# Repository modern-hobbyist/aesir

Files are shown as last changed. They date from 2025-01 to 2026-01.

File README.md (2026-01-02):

# Project Aesir: Custom Keyboard PCB Designs

> ** Many of these boards are still works in progress **

**Project Aesir** is a collection of custom keyboard PCB designs created using KiCad, aimed at keyboard enthusiasts and DIY makers. Each project in this collection was designed to scratch a specific itch, fill a need, or address a particular problem I had with traditional mechanical keyboards, from a template for a standard keyboard PCB using the STM32F072CBT6 microcontroller to a split ergonomic keyboard design with a modular numpad.

I initially started this collection as a personal respository of templates to get my new projects on the ground running faster, but it has gradually grown to include several board designs I've completed. Make sure to check back in periodically as I add new boards to my collection!

## Included Projects
1. **Heimdall**: A full-sized keyboard PCB designed for customization and personal use.
2. **Hermod**: A split ergonomic keyboard design for those seeking an ergonomic, portable build. Featuring a magnetically detachable AND reversible numpad!
3. **Hermod Mk. II**: A remake of the original Hermod with an upgraded STM32G474CET6 MCU, supporting Choc V2 and Gateron KS-33 low profile switches. Including an updated thumb cluster for better ergonomics and an extra key.
3. **Hermod Mk. II - MX**: A remake of the original Hermod, this time with **MX Spacing**. Same as *8Hermod Mk. II** -- supporting Choc V2 and Gateron KS-33 switches.
4. **Hermod Mk. II - MX - North**: Same as **Hermod Mk. II - MX** but with North facing switches for better shine through keycap legend appearance.
5. **Hermod Mk. III**: A continuation of **Hermod Mk. II - MX - North** with several component upgrades for easier/cheaper sourcing (e.g. SRV05-4 for ESD).
6. **Mist**: A full sized keyboard with a new take on the spacebar--replacing it with thumb clusters. It also supports Cherry MX/Gateron Normal Profile or Gateron KS-33 Low Profile Switches.
7. **Mist UDB**: Same as **Mist**, but using a unified daughter board to offload the ESD and USB protection.
8. **Mist UDB - Mk. II**: Same as **Mist UDB** but with proper support for the Gateron Low profile stabilizers as well as standard PCB mount stabilizers via mousebitten PCB cutouts.
3. **STM32F072CBT6 Standard Template**: A blank template for creating your own keyboard designs with the STM32F072CBT6 microcontroller.
4. **STM32F072CBT6 Split Template**: A blank template for creating your own split keyboard designs with the STM32F072CBT6 microcontroller.

## Getting Started

> Note: There may be footprints I've created or manually altered that aren't packaged with this repository, so if you come across something missing, please create an issue and I'll get it updated!

### Requirements
- **KiCad**: Download and install the latest version of [KiCad](https://www.kicad.org/download/).
- **PCB Manufacturer**: These projects were developed in collaboration with PCBWay. Each sub-project will have a link to the project on PCBWay's project sharing platform so you can order them with the click of a button.
- **Plugins**: There are a few KiCad plugins that you can install that will help with building these PCB's as well as one library of keyswitches:
  - [marbastlib Keyswitch Symbol Library](https://github.com/ebastler/marbastlib)
  - [kicad-kbplacer](https://github.com/adamws/kicad-kbplacer)
  - [PCBWay Order Plugin](https://github.com/pcbway/PCBWay-Plug-in-for-Kicad)

### Steps
1. Clone this repository to your local machine.
    ```bash
    git clone https://github.com/modern-hobbyist/aesir
    ```
2. Open the desired KiCad project in your KiCad software.
3. Customize the layout, add your own components, and make any modifications to fit your needs.
4. Export the Gerber files for your chosen PCB manufacturer.
5. Build and assemble your keyboard!

## Contributing
Contributions to **Project Aesir** are welcome! Whether it's improving existing designs, adding new features, or creating entirely new layouts, feel free to open a pull request.

### Contribution Guidelines
1. Fork the repository.
2. Make your changes on a new branch.
3. Submit a pull request with a clear description of your contribution.

## Disclaimer
These designs are provided as-is, without warranty of any kind. I am not liable for any damages, malfunctions, or issues that may arise from using or modifying these designs, including but not limited to hardware damage, injury, or other unintended consequences. By using these designs, you agree to take full responsibility for any results, modifications, or assembly errors.

## License
This project is licensed under the MIT License. See the [LICENSE](LICENSE) file for details.

## Contact
For questions or collaboration inquiries, feel free to create an issue, reach out to me on GitHub or Discord or via my [YouTube channel](https://www.youtube.com/ModernHobbyist).

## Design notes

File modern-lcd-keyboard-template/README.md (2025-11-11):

# Modern LCD Keyboard Template

> **Note:** This PCB is untested. I made updates to this design to address issues I had with the previous version, but I haven't ordered boards, nor have I written the matching firmware for it.

This is a starter template for a Keyboard PCB to help you get started quickly with the right footprints and supplemental components to get it done right.

## Features
- TBD

## Specifications

- **Microcontroller**: STM32G474CETx
- **Key Layout**: Split layout with additional keys for layers and macros.
- **Display**: 2.2" LCD (320x240 resolution) per half.
- **Lighting**: SK6812 Mini RGB LEDs.
- **Switches**: Kailh Choc Low Profile.

## License

This project is licensed under the MIT License. See the [LICENSE](../LICENSE) file for details.

## Acknowledgments

- The QMK community for their amazing firmware.
- Adafruit for the GFX library support.
- Inspiration from the mechanical keyboard enthusiast community.

---

For more information, check out the [Modern Hobbyist YouTube channel](https://www.youtube.com/ModernHobbyist) for videos about this project!

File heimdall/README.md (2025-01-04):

# Heimdall: Full-Sized Custom Keyboard PCB

## Overview
A brief description of the Heimdall project.

## Features
- List of features for the Heimdall keyboard (e.g., full-sized layout, RGB support).

## Requirements
- List of necessary components (e.g., STM32F072CBT6 microcontroller, WS2812B LEDs, etc.).
- Software requirements (e.g., KiCad, QMK firmware).

## Getting Started
1. Clone the repository.
2. Open the project in KiCad.
3. Customize the layout, add components, etc.
4. Export Gerber files and order the PCB.
5. Assemble and program the keyboard.

## Usage
- Instructions on how to use the keyboard, flash firmware, etc.

## Contributing
- Fork the repository.
- Submit a pull request.

## Disclaimer
These designs are provided as-is. I am not liable for any damages or issues.

## License
Licensed under the MIT License. See the [LICENSE](../LICENSE) for more details.

## Contact
For inquiries, contact via GitHub or YouTube.

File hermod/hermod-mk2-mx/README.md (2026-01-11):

# Hermod Mk. II - MX

> **Note:** This PCB is untested. I made updates to this design to address issues I had with the previous version, but I haven't ordered boards, nor have I written the matching firmware for it.

Hermod Mk. II is a redesign of my original Hermod split keyboard, which in turn was my second keyboard design ever! Some issues that were resolved in this version include:
- Better Pin choices for PWM Channels, Mk. I had some issues with timers overlapping
- Added a handedness pin 
  - Allows me to avoid using flash to store handedness
- Switched to Full Duplex split comms
- Mk.I was missing a 5.1kΩ resistor on the split serial line and this switched fixes that.
- Switched to `STM32G474CETx` from the `STM32F072CBT6`
  - More Ram, more flash, more fun. Didn't have enough ram for fun graphics on the LCD
- Added PWM Backlight control for the LCD Display 

Furthermore, this is the **MX Spacing variant**. While it is functionally identically to the Hermod Mk. II, this layout is spaced in a 19.05x19.05 grid, which makes it compatible with the [Tai-Hao keycaps](https://shop.tai-hao.com/products/98white-1) highlighted in the ZSA Voyager.

## Features

- **Split Design**: Ergonomic split layout for improved typing comfort.
- **Detachable Numpad**: Magnetically detachable and reversible numpad that can connect to either half.
- **Dual LCD Displays**: Each half features a 2.2" LCD for customizable graphics and real-time information.
- **QMK Firmware**: Fully programmable and customizable using QMK.
- **Per-Key RGB Lighting**: Vibrant, individually addressable RGB LEDs for endless customization.
- **Hot-Swappable Switch Sockets**: Easily swap out switches without soldering.
- **Open Source Hardware**: Schematics and design files available for personal customization.

## Specifications

- **Microcontroller**: STM32G474CETx
- **Key Layout**: Split layout with additional keys for layers and macros.
- **Display**: 2.2" LCD (320x240 resolution) per half.
- **Lighting**: SK6812 Mini RGB LEDs.
- **Switches**: Kailh Choc Low Profile.

## License

This project is licensed under the MIT License. See the [LICENSE](../LICENSE) file for details.

## Acknowledgments

- The QMK community for their amazing firmware.
- Adafruit for the GFX library support.
- Inspiration from the mechanical keyboard enthusiast community.

---

For more information, check out the [Modern Hobbyist YouTube channel](https://www.youtube.com/ModernHobbyist) for videos about this project!

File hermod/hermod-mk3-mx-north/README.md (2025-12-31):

# Hermod Mk. III - MX North

> **Note:** This PCB is untested. I made updates to this design to address issues I had with the previous version, but I haven't ordered boards, nor have I written the matching firmware for it.

Hermod Mk. III is a redesign of my original Hermod split keyboard. Some issues that were resolved in this version include:
- Updated from the PRTR5V0U2X,215 to the SRV05-4 since the former is out of stock everywhere.

Furthermore, this is the **NORTH FACING** MX Spacing variant. While it is functionally identically to the Hermod Mk. II, this layout is spaced in a 19.05x19.05 grid, which makes it compatible with the [Tai-Hao keycaps](https://shop.tai-hao.com/products/98white-1) highlighted in the ZSA Voyager. Also, the switches are rotated 180• from the previous versions so that the LED's are better aligned with shine-through keycaps. 

**Note:** This keyboard supports KS-33 and Choc V2 switches in an MX spacing. It does not support standard MX or Gateron switches. The reasoning for that is that this keyboard was intended to be as low profile as possible (e.g. USB C midmount instead of standard USB C sockets). 

## SMD BOMs
These BOMs exclude the switch hotswap sockets, purchase your sockets of choice (either KS-33 HS or Choc V2 HS sockets)
- Left: https://www.digikey.com/en/mylists/list/ACSWS99OKK
- Right: https://www.digikey.com/en/mylists/list/SVQS1DIITH
- Numpad: 
  - Just need 20x Diodes for the switches: https://www.digikey.com/en/products/detail/mcc-micro-commercial-components/1N4148W-TP/717196
  
## Hardware BOM
- TODO

## Features

- **Split Design**: Ergonomic split layout for improved typing comfort.
- **Detachable Numpad**: Magnetically detachable and reversible numpad that can connect to either half.
- **Dual LCD Displays**: Each half features a 2.2" LCD for customizable graphics and real-time information.
- **QMK Firmware**: Fully programmable and customizable using QMK.
- **Per-Key RGB Lighting**: Idividually addressable RGB LEDs for endless customization.
- **Hot-Swappable Switch Sockets**: Easily swap out switches without soldering.
- **Open Source Hardware**: Schematics and design files available for personal customization.
- **Combo Switch Footprints**: Choose between KS-33 or Choc V2 hotswap sockets.

## Specifications

- **Microcontroller**: STM32G474CET6
- **Key Layout**: Split layout with additional keys for layers and macros.
- **Display**: 2.2" LCD (320x240 resolution) per half.
- **Lighting**: SK6812 Mini RGB LEDs.
- **Switches**: Kailh Choc Low Profile.

## License

This project is licensed under the MIT License. See the [LICENSE](../LICENSE) file for details.

## Acknowledgments

- The QMK community for their amazing firmware.
- Adafruit for the GFX library support.
- Inspiration from the mechanical keyboard enthusiast community.

---

For more information, check out the [Modern Hobbyist YouTube channel](https://www.youtube.com/ModernHobbyist) for videos about this project!

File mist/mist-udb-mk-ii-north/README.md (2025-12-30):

# Mist

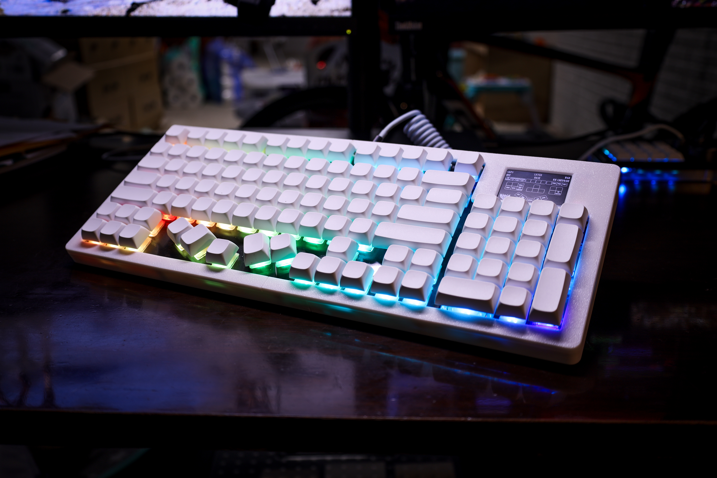
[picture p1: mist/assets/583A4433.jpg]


**Mist** is my take on a full size keyboard, but with some upgrades I carried over from my second keyboard build--**[Hermod](https://github.com/modern-hobbyist/aesir/tree/main/hermod-mk2)**. Furthermore, this is the UDB version of **Mist**, which stands for Unified Daughter Board

Aside from the UDB connector and the lack of USB-C/on-board ESD protection circuitry, this keyboard is functionally identical to the base **Mist** keyboard.

This project is open source, so I'll do my best to keep it updated as questions come in. I can't guarantee I'll always have time to respond, but if you have questions you can reach out on [my Discord server](https://discord.gg/68WXGsjqJp) or on the [Keyboard Atelier Discord](https://discord.gg/b7vwhHS).

## Why?

1. First of all, I'm addicted to designing custom keyboards now, so jot that down.
2. I have two children now, and while I love my split keyboard, typing with one hand is 100 times more difficult and time consuming on a split.
3. Related to above, I wanted a keyboard that would appeal to the non-split community, but also incorporated all the features I loved mose about my split build.

## Features

- **2.2" LCD Display**: A 2.2" LCD Display to show keyboard state, stats, and any fun animations I can think of.
- **Thumb Clusters in Place of Spacebar**: I loved the thumb clusters from my split keyboard and the giant spacebar is such a waste of space!
- **Connector for Unified Daughter Board**: A Unified Daughter Board extracts all the ESD and over-voltage protection from the main PCB and allows for more complex case shapes.
- **Per-Key RGB Lighting**: Vibrant, individually addressable RGB LEDs for endless customization.
- **KS-33 + MX/Gateron Normal Profile Hot-Swappable Switch Sockets**: Support for either KS-33 low-profile or MX style (Cherry or Gateron Normal profile) switches.
- **QMK Firmware**: Fully programmable and customizable using QMK.
- **Standard QWERTY Layout and Keymap**: The layout we all grew up learning to type on!

## Specifications

- **Microcontroller**: STM32G474RETx
- **Display**: 2.2" LCD (320x240 resolution) per half.
- **Lighting**: SK6812 Mini RGB LEDs.

## BOM
> Note: I have not finished building a KS-33 version of this keyboard. However, the only difference is the hotswap sockets you use (and the corresponding switches/keycaps). Also, there shouldn't be any issue using the existing case design with the KS-33 version.

### Electronics

- [Digikey Parts LIst](https://www.digikey.com/en/mylists/list/XUNNWUFIT7)
- [ILI9341 LCD](https://www.aliexpress.us/item/2255800032844649.html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)
- [PCBWay Project](https://www.pcbway.com/project/shareproject/Custom_Mechanical_Keyboard_7a40c23a.html)
  - > Note: If you are ordering assembled PCBs from the PCBWay Project, it may take a few cycles to smooth out any BOM hiccups.
- [Unified Daughter Board](https://cannonkeys.com/products/unified-daughterboard-and-jst-cable?variant=41613867843695)
- [Hotswap Sockets I used](https://www.aliexpress.us/item/3256807081236706.html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)
- [Keycaps I used](https://www.aliexpress.us/item/3256805029855838.html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)
- [Switches of Choice](https://a.co/d/3fji9Gi)
- [Stabilizers of CHoice](https://a.co/d/hJjX7h8)

### Hardware

- [1.5mm Acrylic Sheet](https://a.co/d/8NMezDu)
- [M3x8mm Bolts - x13](https://boltdepot.com/Product-Details?product=13635)
- [M3 Nuts - x4](https://boltdepot.com/Product-Details?product=4773)
- [Heatset Inserts - M3x3mm](https://a.co/d/18Dypq1)
- [3mm Poron Sheet](https://www.aliexpress.us/item/3256804497716681.html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)
- [18x3x3mm gaskets](https://www.aliexpress.us/item/3256804012735285.html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)
- [M2x6mm Nylon Standoffs](https://www.aliexpress.us/item/3256808418665069.html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) - Female - Female
- [M2x3mm screws](https://www.aliexpress.us/item/3256807746050750.html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)
- [8mm Steel Rods](https://a.co/d/39idH9k)

# Tools

- [Heat Set Insert tips](https://a.co/d/3we9tOl)
- 3d Printer
- Allen Wrenches
- Razor Blade
- Soldering Iron
- Computer
- USB C Cable
- Super Glue

## License

This project is licensed under the MIT License. See the [LICENSE](../LICENSE) file for details.

## Acknowledgments

- The QMK community for their amazing firmware.
- Adafruit for the GFX library support.
- Inspiration from the mechanical keyboard enthusiast community.

---

For more information, check out the [Modern Hobbyist YouTube channel](https://www.youtube.com/ModernHobbyist) for videos about this project!

> Also, please let me know in an issue or on Discord if there are issues with this board or the supplementary files so I can get them updated!

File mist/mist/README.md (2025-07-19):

# Mist

> **Note:** This PCB is untested. I am working on getting an order together, but until I can verify it functions as expected, use at your own risk.

**Mist** is my take on a full size keyboard, but with some upgrades I carried over from my second keyboard build--**Hermod**.

## Why?
1. First of all, I've addicted to designing custom keyboards now, so jot that down.
2. I have two children now, and while I love my split keyboard, typing with one hand is 100 times more difficult and time consuming on a split.
3. Related to above, I wanted a keyboard that would appeal to the non-split community, but also incorporated all the features I loved mose about my split build.

## Features

- **2.2" LCD Display**: A 2.2" LCD Display to show keyboard state, stats, and any fun animations I can think of.
- **Thumb Clusters in Place of Spacebar**: I loved the thumb clusters from my split keyboard and the giant spacebar is such a waste of space!
- **Per-Key RGB Lighting**: Vibrant, individually addressable RGB LEDs for endless customization.
- **KS-33 + MX/Gateron Normal Profile Hot-Swappable Switch Sockets**: Support for either KS-33 low-profile or MX style (Cherry or Gateron Normal profile) switches.
- **QMK Firmware**: Fully programmable and customizable using QMK.
- **Standard QWERTY Layout and Keymap**: The layout we all grew up learning to type on!

## Specifications

- **Microcontroller**: STM32G474RETx
- **Display**: 2.2" LCD (320x240 resolution) per half.
- **Lighting**: SK6812 Mini RGB LEDs.

## License

This project is licensed under the MIT License. See the [LICENSE](../LICENSE) file for details.

## Acknowledgments

- The QMK community for their amazing firmware.
- Adafruit for the GFX library support.
- Inspiration from the mechanical keyboard enthusiast community.

---

For more information, check out the [Modern Hobbyist YouTube channel](https://www.youtube.com/ModernHobbyist) for videos about this project!

> Also, please let me know in an issue or on Discord if there are issues with this board or the supplementary files so I can get them updated!

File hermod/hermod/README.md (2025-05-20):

# Hermod Split Keyboard

Hermod is a feature-rich, fully customizable split mechanical keyboard designed for enthusiasts who want the ultimate typing experience. With per-key RGB lighting, dual 2.2" LCD displays, and QMK firmware compatibility, Hermod is both functional and visually stunning.

## Features

- **Split Design**: Ergonomic split layout for improved typing comfort.
- **Detachable Numpad**: Magnetically detachable and reversible numpad that can connect to either half.
- **Dual LCD Displays**: Each half features a 2.2" LCD for customizable graphics and real-time information.
- **QMK Firmware**: Fully programmable and customizable using QMK.
- **Per-Key RGB Lighting**: Vibrant, individually addressable RGB LEDs for endless customization.
- **Hot-Swappable Switch Sockets**: Easily swap out switches without soldering.
- **Open Source Hardware**: Schematics and design files available for personal customization.

## Specifications

- **Microcontroller**: STM32F072CBT6
- **Key Layout**: Split layout with additional keys for layers and macros.
- **Display**: 2.2" LCD (320x240 resolution) per half.
- **Lighting**: SK6812 Mini RGB LEDs.
- **Switches**: Kailh Choc Brown

## Instructions

I haven't yet written out full instructions for this keyboard, but the appropriate BOM and Pick-and-place files should be present to have PCBWay assemble it for you. From there, it's really just a matter of printing all the parts, ordering the right display, switches, keycaps and bolts, then putting it all together!

The firmware is slightly tricky, as each half needs to be flashed with a left or right specific firmware, so I'll try to get instructions for that written soon.

For the time being, here is a link to the latest firmware:
https://github.com/modern-hobbyist/qmk_userspace/releases/tag/latest

## Contributing

Contributions are welcome! Whether you have ideas for features, bug fixes, or design improvements, feel free to open an issue or submit a pull request.

## License

This project is licensed under the MIT License. See the [LICENSE](../LICENSE) file for details.

## Acknowledgments

- The QMK community for their amazing firmware.
- Adafruit for the GFX library support.
- Inspiration from the mechanical keyboard enthusiast community.

---

For more information, check out the [Modern Hobbyist YouTube channel](https://www.youtube.com/ModernHobbyist) for videos about this project!

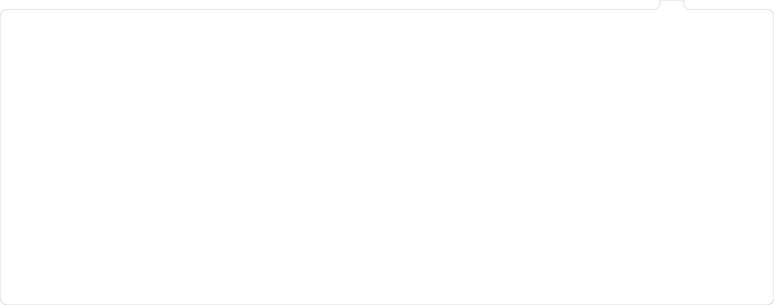
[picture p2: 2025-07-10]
mist/assets/mist-edge-cut-11.png

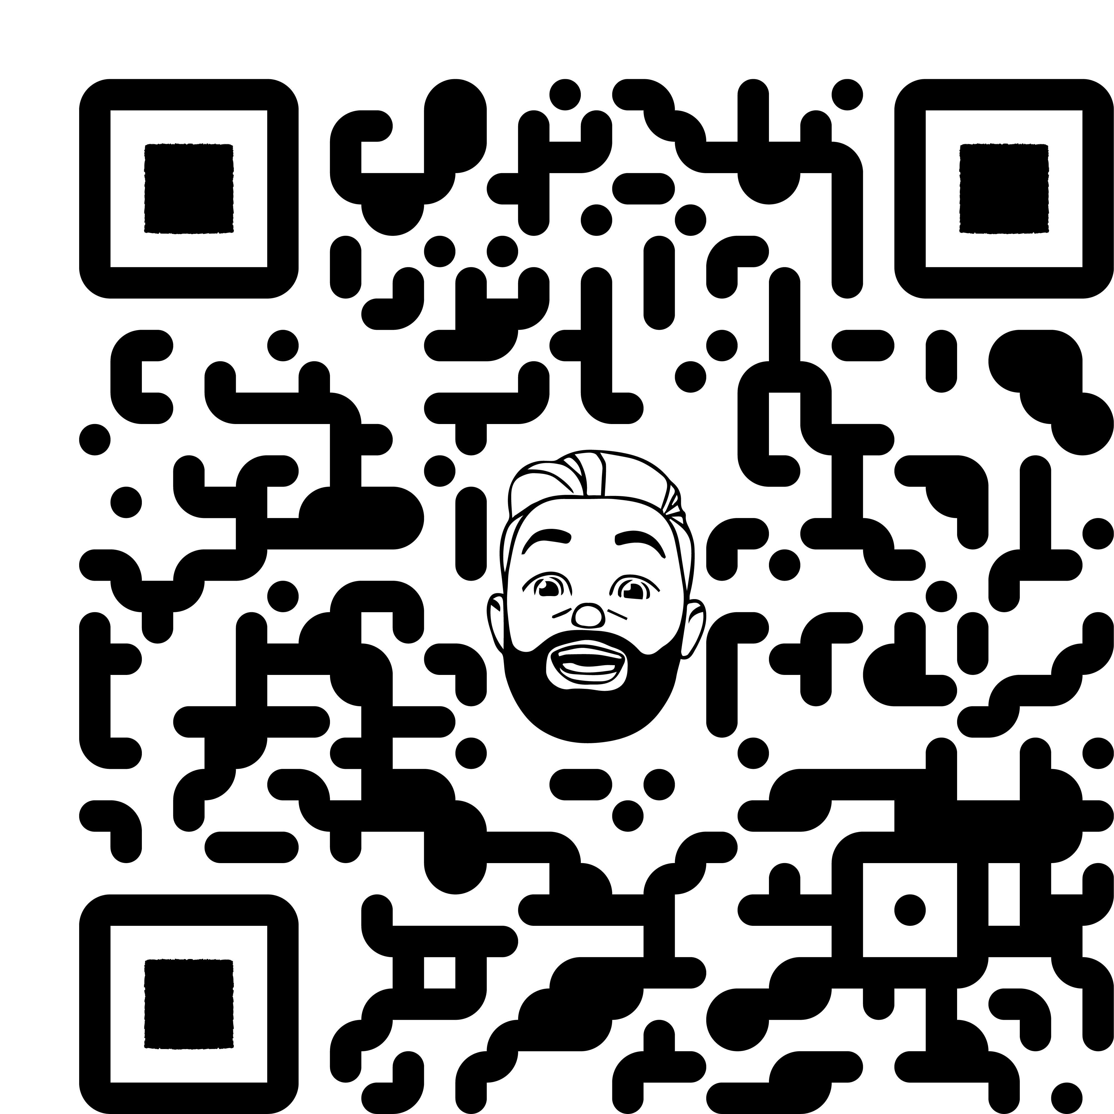
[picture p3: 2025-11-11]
YouTube QR.png

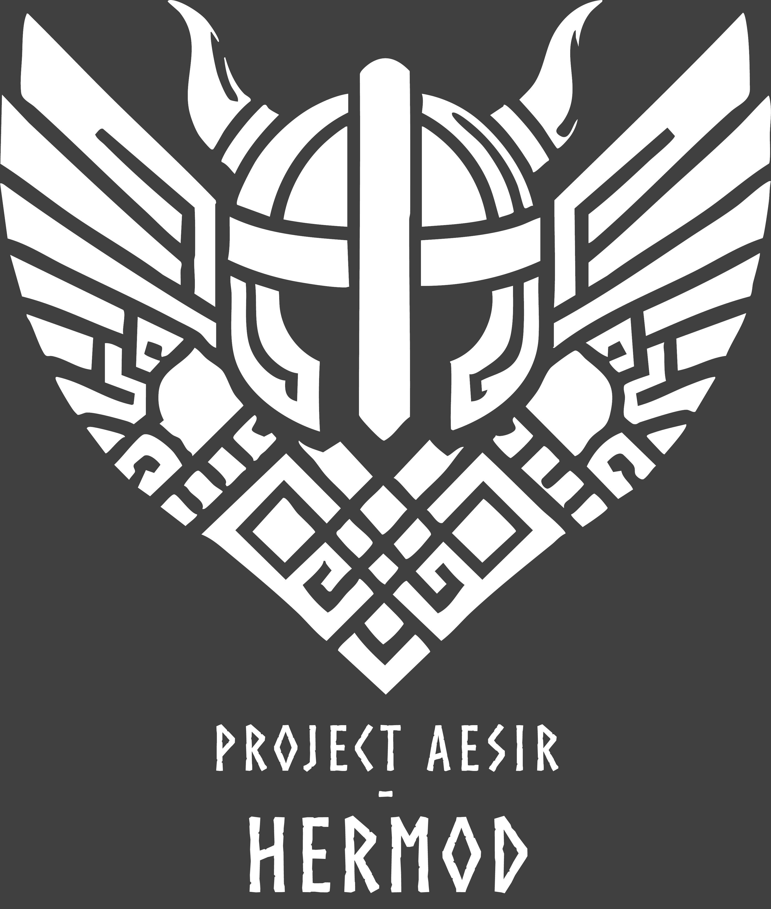
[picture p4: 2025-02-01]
hermod/assets/Asset 11.png

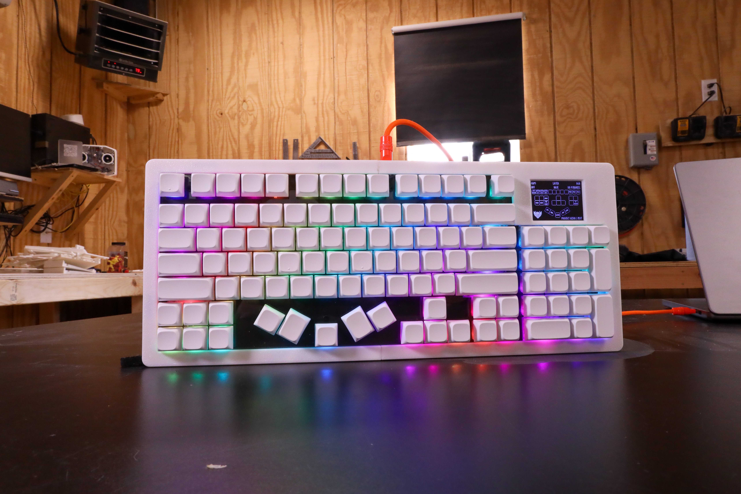
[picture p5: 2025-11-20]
mist/assets/583A4316.jpeg

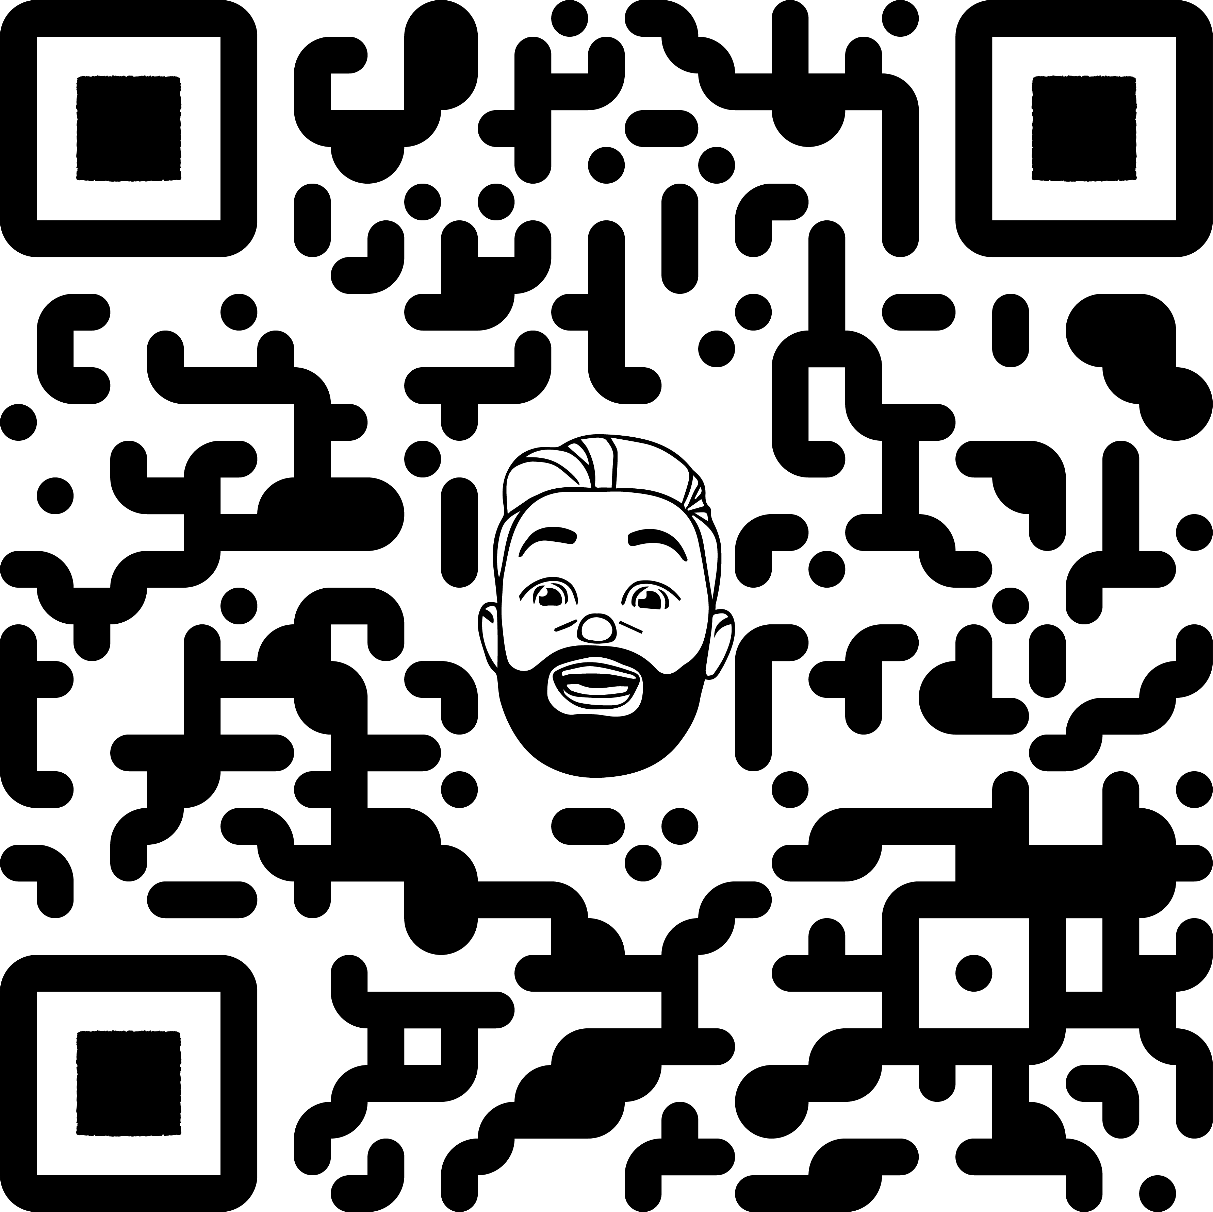
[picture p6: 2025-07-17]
hermod/assets/Asset 31.png

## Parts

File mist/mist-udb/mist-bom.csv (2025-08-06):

Id | Designator | Footprint | Quantity | Designation | Supplier and ref
1 | S4,S6,S7,S5 | STAB_MX_P_2u | 4 | MX_stab
2 | S1,S3 | STAB_MX_P_2.25u | 2 | MX_stab
3 | S2 | STAB_MX_P_2.75u | 1 | MX_stab
4 | U4 | CR2013-MI2120 | 1 | CR2013-MI2120
5 | J2 | PinHeader_1x05_P2.54mm_Vertical | 1 | Conn_01x05
6 | LED44,LED6,LED33,LED8,LED2,LED82,LED25,LED102,LED81,LED49,LED61,LED38,LED17,LED60,LED96,LED52,LED10,LED32,LED22,LED1,LED55,LED40,LED46,LED103,LED83,LED26,LED15,LED36,LED69,LED27,LED21,LED45,LED11,LED68,LED66,LED79,LED86,LED71,LED80,LED100,LED63,LED56,LED16,LED73,LED67,LED72,LED65,LED43,LED31,LED13,LED37,LED89,LED85,LED34,LED76,LED48,LED94,LED84,LED41,LED58,LED28,LED24,LED87,LED74,LED78,LED70,LED9,LED20,LED30,LED75,LED88,LED4,LED3,LED97,LED53,LED12,LED51,LED14,LED29,LED50,LED98,LED19,LED42,LED5,LED23,LED77,LED18,LED90,LED99,LED93,LED101,LED7,LED64,LED95,LED39,LED91,LED54,LED57,LED59,LED35,LED62,LED92,LED47 | LED_choc_6028R | 103 | choc_SK6812MINI-E
7 | C51,C20,C81,C50,C57,C45,C60,C100,C87,C112,C11,C99,C27,C32,C102,C18,C47,C86,C46,C91,C14,C24,C19,C101,C76,C16,C97,C65,C23,C72,C75,C77,C29,C43,C33,C89,C40,C36,C71,C66,C35,C52,C63,C53,C41,C59,C30,C62,C61,C15,C54,C88,C73,C64,C12,C80,C82,C1,C39,C70,C5,C13,C79,C9,C92,C56,C94,C83,C38,C25,C21,C48,C84,C95,C31,C2,C3,C37,C26,C69,C10,C44,C55,C93,C8,C49,C6,C7,C4,C17,C68,C74,C96,C98,C85,C42,C90,C34,C78,C22,C67,C103,C28,C58 | C_0402_1005Metric | 104 | 0.1uF
8 | CH91,CH60,CH96,CH73,CH49,CH46,CH33,CH18,CH58,CH20,CH36,CH45,CH47,CH92,CH32,CH39,CH11,CH70,CH35,CH103,CH24,CH72,CH8,CH31,CH1,CH100,CH4,CH52,CH86,CH57,CH102,CH53,CH75,CH93,CH69,CH14,CH41,CH27,CH68,CH2,CH98,CH76,CH61,CH84,CH85,CH19,CH50,CH87,CH80,CH5,CH63,CH42,CH22,CH99,CH30,CH13,CH28,CH95,CH67,CH21,CH16,CH89,CH77,CH74,CH51,CH23,CH59,CH54,CH79,CH34,CH25,CH78,CH3,CH15,CH37,CH83,CH88,CH64,CH12,CH66,CH48,CH6,CH81,CH65,CH56,CH44,CH40,CH90,CH71,CH82,CH10,CH7,CH94,CH9,CH26,CH17,CH55,CH38,CH62,CH43,CH101,CH97,CH29 | KS-33_MX-Hotswap-1U | 103 | KS33_SW_HS
9 | D25,D27,D89,D71,D76,D78,D96,D17,D58,D72,D95,D10,D16,D47,D23,D13,D87,D69,D70,D52,D92,D3,D34,D81,D14,D66,D21,D33,D85,D56,D30,D83,D74,D104,D9,D43,D19,D59,D11,D84,D1,D53,D20,D105,D50,D80,D12,D77,D55,D60,D28,D93,D100,D15,D32,D37,D94,D26,D73,D18,D8,D68,D2,D46,D103,D64,D39,D42,D75,D29,D22,D79,D49,D99,D44,D98,D88,D51,D6,D57,D86,D45,D7,D5,D31,D54,D61,D62,D101,D35,D48,D36,D102,D63,D67,D97,D38,D90,D91,D24,D4,D82,D65 | D_SOD-123 | 103 | D
10 | C120,C130,C121 | C_0805_2012Metric | 3 | 100n
11 | C127,C128 | C_0402_1005Metric | 2 | 1uF
12 | C107,C104,C108,C109,C105,C106,C110 | C_0402_1005Metric | 7 | 100nF
13 | U6 | SOT95P280X145-5N | 1 | SN74AHCT1G125DBVR
14 | R7 | R_0805_2012Metric | 1 | 120
15 | J1 | Molex_Pico-EZmate_78171-0004_1x04-1MP_P1.20mm_Vertical | 1 | 78171-0004
16 | D41,D40 | D_SOD-123 | 2 | 1N4148
17 | Q3 | SOT-23-3 | 1 | MMUN2133LT1G
18 | RESET1 | SW_SPST_TL3342 | 1 | DFU
19 | R8,R9 | R_0805_2012Metric | 2 | 68k
20 | U5 | LQFP-64_10x10mm_P0.5mm | 1 | STM32G474RETx
21 | U3 | SOT-23 | 1 | XC6206PxxxMR-Regulator_Linear

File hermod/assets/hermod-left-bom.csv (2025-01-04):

Id | Designator | Footprint | Quantity | Designation | Supplier and ref
1 | U7,U6 | Pogo_2.54mm_5p | 2 | ~
2 | U4 | CR2013-MI2120 | 1 | CR2013-MI2120
3 | J2 | PinHeader_1x05_P2.54mm_Vertical | 1 | Conn_01x05
4 | CH17,CH14,CH33,CH11,CH12,CH21,CH5,CH6,CH31,CH26,CH24,CH27,CH25,CH20,CH7,CH8,CH1,CH19,CH10,CH34,CH22,CH3,CH36,CH4,CH13,CH29,CH35,CH18,CH15,CH37,CH32,CH28 | SW_choc_v1_HS_CPG135001S30_1u | 32 | choc_v1_SW_HS
5 | LED36,LED13,LED21,LED32,LED23,LED2,LED20,LED1,LED38,LED29,LED33,LED30,LED18,LED19,LED17,LED8,LED39,LED15,LED24,LED16,LED3,LED4,LED5,LED26,LED27,LED31,LED25,LED9,LED12,LED22,LED34,LED6,LED10,LED11,LED7,LED35,LED28,LED14,LED37 | LED_choc_6028R | 39 | choc_SK6812MINI-E
6 | D2,D33,D28,D20,D1,D36,D30,D22,D39,D14,D24,D13,D12,D19,D16,D25,D11,D3,D37,D15,D18,D23,D34,D21,D6,D5,D35,D4,D31,D29,D38,D10,D26,D8,D17,D7,D32,D9,D27 | D_SOD-123 | 39 | D
7 | C106,C104,C109,C100,C102,C105,C103 | C_0402_1005Metric | 7 | 100nF
8 | C10,C28,C19,C43,C11,C20,C34,C33,C44,C36,C23,C27,C32,C22,C21,C6,C37,C14,C3,C39,C18,C9,C7,C15,C30,C38,C24,C29,C25,C4,C26,C35,C8,C12,C16,C5,C17,C31,C1,C13,C2 | C_0402_1005Metric | 41 | 0.1uF
9 | Q1 | SOT-23-3 | 1 | AO3401A
10 | CH16,CH38,CH23,CH30,CH2,CH39,CH9 | SW_choc_v1_HS_CPG135001S30_1.5u | 7 | choc_v1_SW_HS
11 | RST1,BOOT1 | SW_SPST_TL3342 | 2 | SW_SPST
12 | R2,R3,R1,R4 | R_0402_1005Metric | 4 | 5.1k
13 | C101 | C_0603_1608Metric | 1 | 10uF
14 | C107,C108 | C_0402_1005Metric | 2 | 1uF
15 | F1 | Fuse_1206_3216Metric | 1 | 500mA
16 | U5 | SOT-363_SC-70-6_Handsoldering | 1 | TXB0101
17 | U2 | SOT-143 | 1 | PRTR5V0U2X
18 | U1 | LQFP-48_7x7mm_P0.5mm | 1 | STM32F072CBT6
19 | J1,J3 | USB_C_Receptacle_HRO_TYPE-C-31-M-14 | 2 | USB_C_Receptacle_USB2.0
20 | U3 | SOT-23 | 1 | XC6206PxxxMR-Regulator_Linear
21 | Q2 | SOT-23-3 | 1 | MMUN2233LT1G

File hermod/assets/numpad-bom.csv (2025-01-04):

Id | Designator | Footprint | Quantity | Designation | Supplier and ref
1 | U1,U2 | Pogo_2.54mm_5p | 2 | ~
2 | D3,D2,D20,D5,D10,D13,D6,D9,D14,D16,D7,D18,D11,D4,D17,D1,D8,D15,D12,D19 | D_SOD-123 | 20 | D
3 | CH20,CH2,CH18,CH3,CH5,CH12,CH9,CH10,CH14,CH11,CH19,CH17,CH6,CH8,CH1,CH16,CH7,CH13,CH15,CH4 | SW_choc_v1_HS_CPG135001S30_1u | 20 | choc_v1_SW_HS

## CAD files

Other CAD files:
hermod/hermod-mk2-mx-north/hermod-numpad/numpad-B_Paste.dxf
hermod/hermod-mk2-mx/hermod-numpad/numpad-B_Paste.dxf
hermod/hermod-mk2/hermod-numpad/numpad-B_Paste.dxf
hermod/hermod-mk3-mx-north/hermod-numpad/numpad-B_Paste.dxf
hermod/hermod/hermod-numpad/numpad-B_Paste.dxf

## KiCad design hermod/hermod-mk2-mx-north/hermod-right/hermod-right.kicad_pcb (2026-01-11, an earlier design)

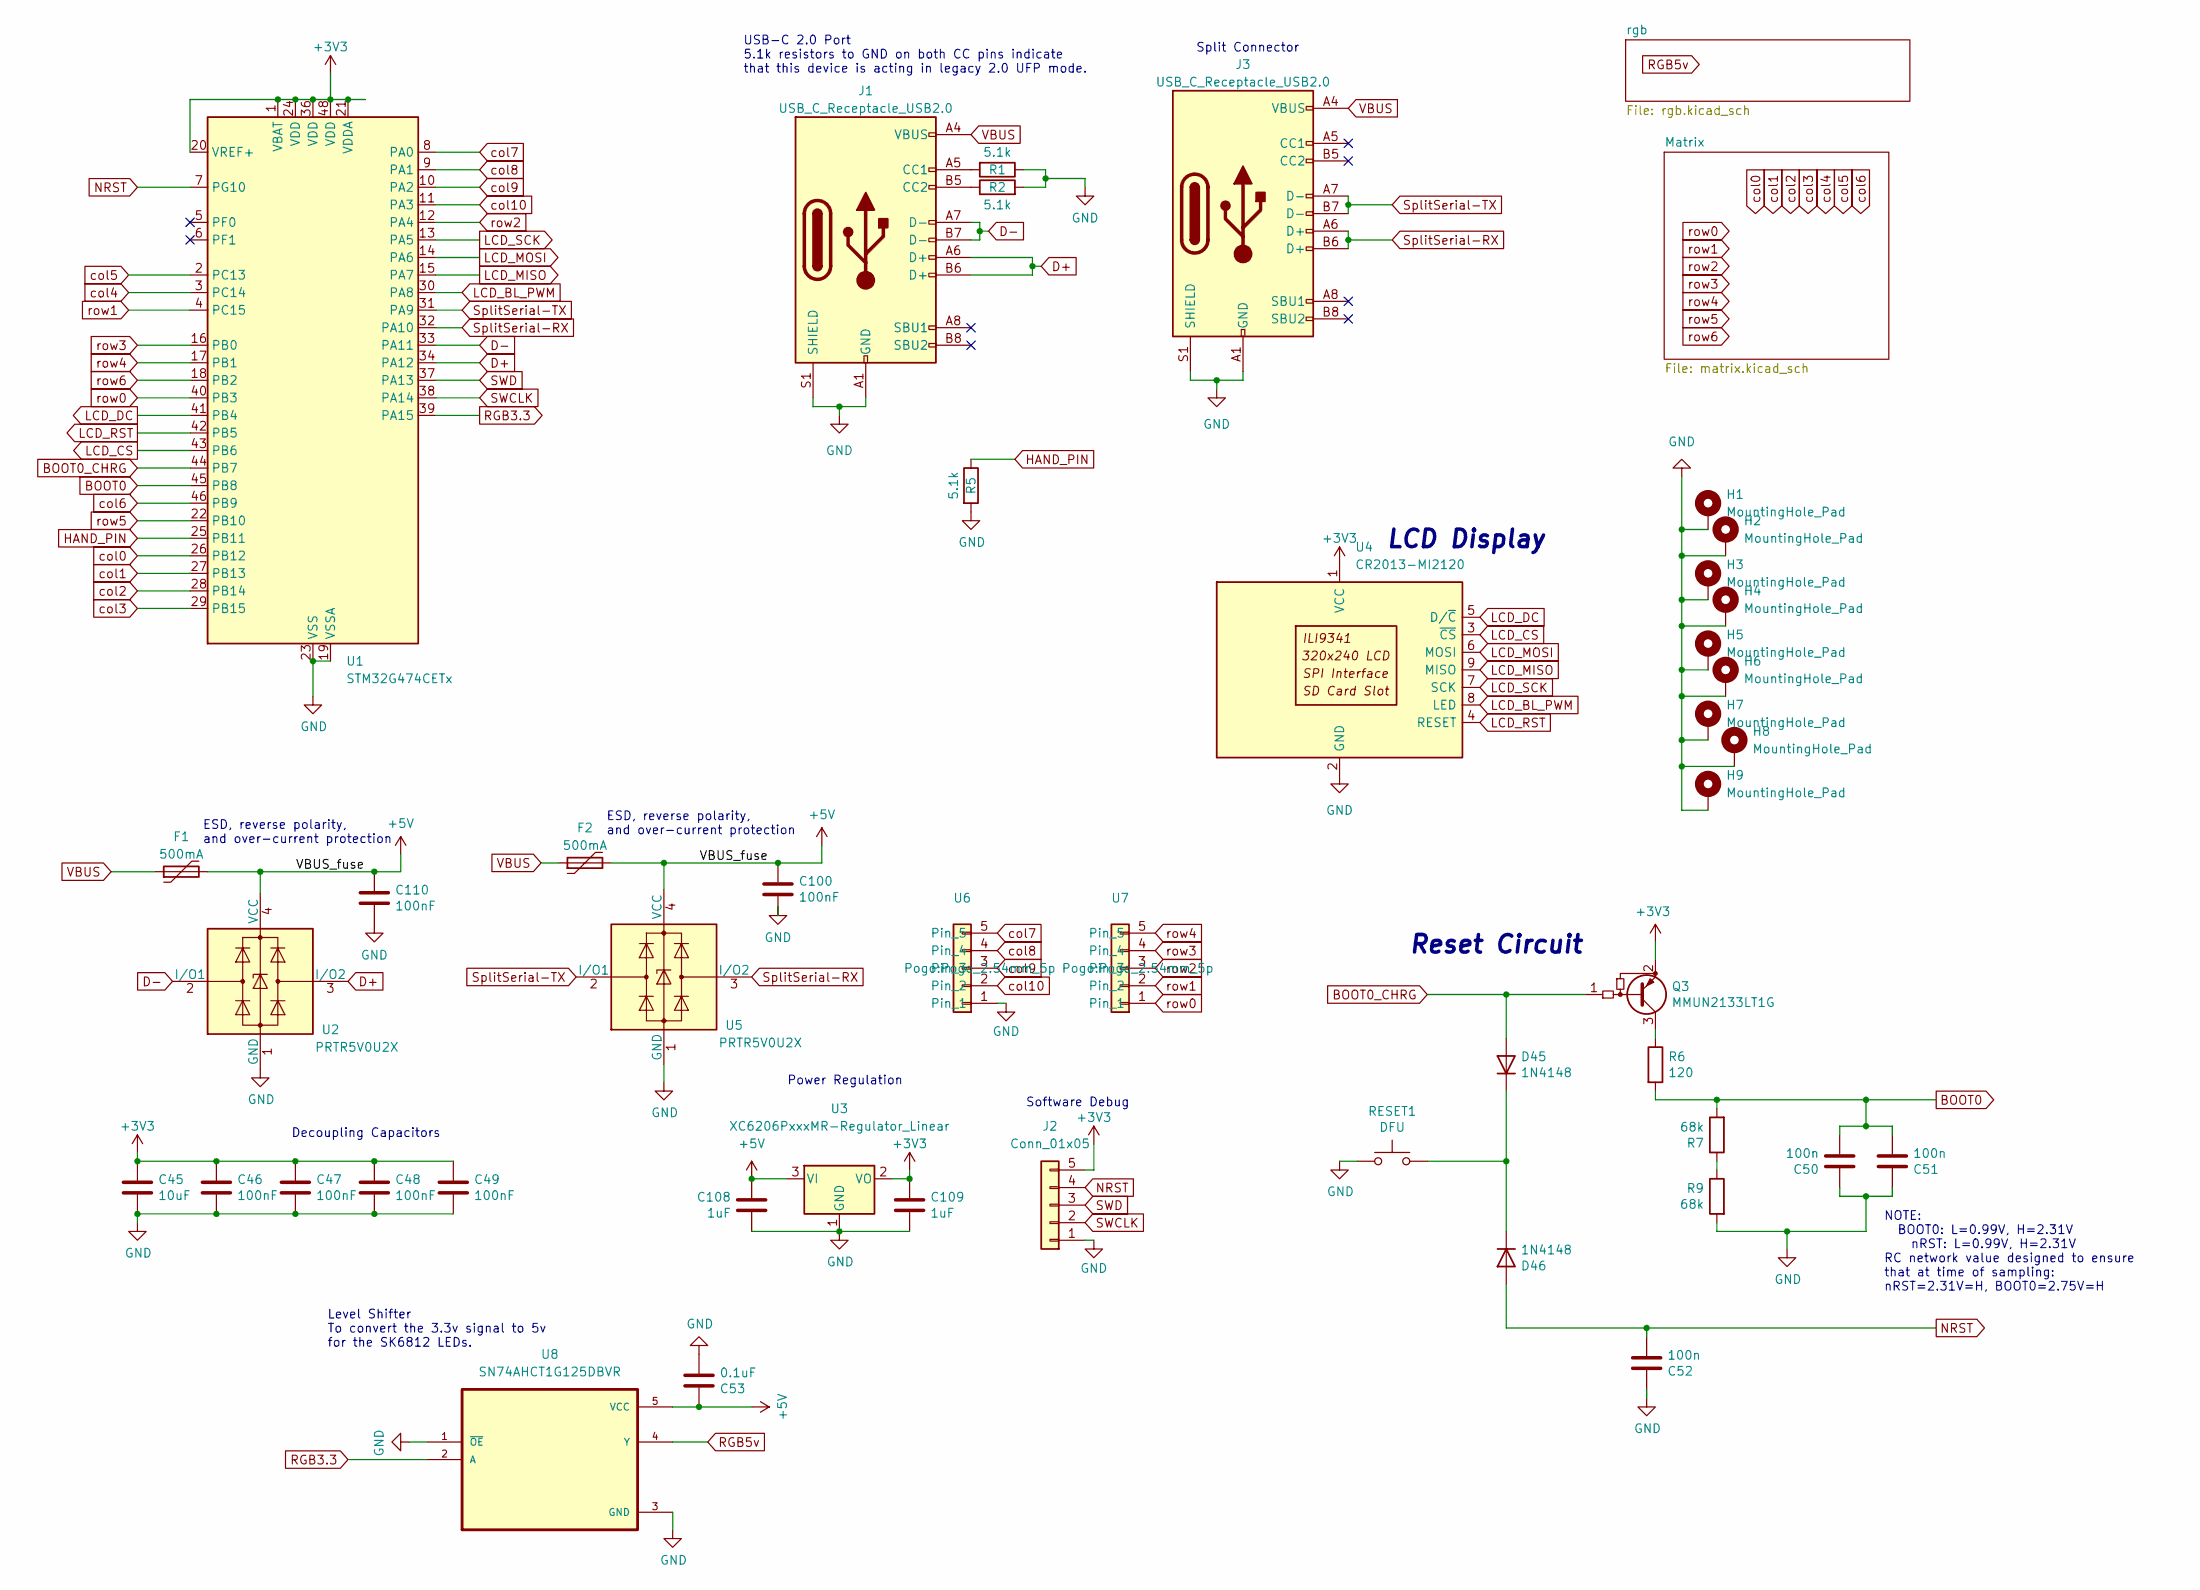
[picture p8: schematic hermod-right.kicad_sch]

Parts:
C45: 10uF; C_0603_1608Metric; LCSC C307331
C46, C47, C48, C49, C100, C110: 100nF; C_0402_1005Metric; LCSC C307331
C50, C51, C52: 100n; C_0805_2012Metric
C53: 0.1uF; C_0402_1005Metric; LCSC C307331
C108, C109: 1uF; C_0402_1005Metric; LCSC C307331
D45, D46: 1N4148; D_SOD-123
F1, F2: 500mA; Fuse_1206_3216Metric; LCSC C135341
H1, H2, H3, H4, H5, H6, H7, H8, H9: MountingHole_Pad; MountingHole_3.2mm_M3_DIN965_Pad
J1, J3: USB_C_Receptacle_USB2.0; USB_C_Receptacle_HRO_TYPE-C-31-M-14; JlcRotOffset 180
J2: Conn_01x05; PinHeader_1x05_P2.54mm_Vertical
Q3: MMUN2133LT1G; SOT-23-3
R1, R2, R5: 5.1k; R_0402_1005Metric
R6: 120; R_0805_2012Metric
R7, R9: 68k; R_0805_2012Metric
RESET1: DFU; SW_SPST_TL3342
U1: STM32G474CETx; LQFP-48_7x7mm_P0.5mm
U2, U5: PRTR5V0U2X; SOT-143; LCSC C2827688
U3: XC6206PxxxMR-Regulator_Linear; SOT-23; LCSC C5446
U4: CR2013-MI2120
U6, U7: Pogo_2.54mm_5p
U8: SN74AHCT1G125DBVR; SOT95P280X145-5N

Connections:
+3V3: C45.1, C46.1, C47.1, C48.1, C49.1, C109.1, J2.5, Q3.2 (E), U1.1 (VBAT), U1.20 (VREF+), U1.21 (VDDA), U1.24 (VDD), U1.36 (VDD), U1.48 (VDD), U3.2 (VO), U4.1 (VCC)
+5V: C53.1, C100.1, C108.1, C110.1, F1.2, F2.2, U2.4 (VCC), U3.3 (VI), U5.4 (VCC), U8.5 (VCC); also elsewhere on the board
BOOT0: C50.2, C51.2, R6.2, R7.2, U1.45 (PB8)
BOOT0_CHRG: D45.2 (A), Q3.1 (B), U1.44 (PB7)
D+: J1.A6 (D+), J1.B6 (D+), U1.34 (PA12), U2.3 (I/O2)
D-: J1.A7 (D-), J1.B7 (D-), U1.33 (PA11), U2.2 (I/O1)
GND: C45.2, C46.2, C47.2, C48.2, C49.2, C50.1, C51.1, C52.1, C53.2, C100.2, C108.2, C109.2, C110.2, H1.1, H2.1, H3.1, H4.1, H5.1, H6.1, H7.1, H8.1, H9.1, J1.A1 (GND), J1.A12 (GND), J1.B1 (GND), J1.B12 (GND), J1.S1 (SHIELD), J2.1, J3.A1 (GND), J3.A12 (GND), J3.B1 (GND), J3.B12 (GND), J3.S1 (SHIELD), R1.1, R2.2, R5.2, R9.2, RESET1.1, U1.19 (VSSA), U1.23 (VSS), U1.35 (VSS), U1.47 (VSS), U2.1 (GND), U3.1 (GND), U4.2 (GND), U5.1 (GND), U6.1, U8.1 (~OE), U8.3 (GND); also elsewhere on the board
HAND_PIN: R5.1, U1.25 (PB11)
LCD_BL_PWM: U1.30 (PA8), U4.8 (LED)
LCD_CS: U1.43 (PB6), U4.3 (~CS)
LCD_DC: U1.41 (PB4), U4.5 (D/~C)
LCD_MISO: U1.15 (PA7), U4.9 (MISO)
LCD_MOSI: U1.14 (PA6), U4.6 (MOSI)
LCD_RST: U1.42 (PB5), U4.4 (RESET)
LCD_SCK: U1.13 (PA5), U4.7 (SCK)
NRST: C52.2, D46.2 (A), J2.4, U1.7 (PG10)
unnamed: D45.1 (K), D46.1 (K), RESET1.2
unnamed: J1.A5 (CC1), R1.2
unnamed: J1.B5 (CC2), R2.1
unnamed: Q3.3 (C), R6.1
unnamed: R7.1, R9.1
RGB3.3: U1.39 (PA15), U8.2 (A)
RGB5v: U8.4 (Y); also elsewhere on the board
SWCLK: J2.2, U1.38 (PA14)
SWD: J2.3, U1.37 (PA13)
SplitSerial-RX: J3.A6 (D+), J3.B6 (D+), U1.32 (PA10), U5.3 (I/O2)
SplitSerial-TX: J3.A7 (D-), J3.B7 (D-), U1.31 (PA9), U5.2 (I/O1)
VBUS: F1.1, F2.1, J1.A4 (VBUS), J1.A9 (VBUS), J1.B4 (VBUS), J1.B9 (VBUS), J3.A4 (VBUS), J3.A9 (VBUS), J3.B4 (VBUS), J3.B9 (VBUS)
col0: U1.26 (PB12); also elsewhere on the board
col1: U1.27 (PB13); also elsewhere on the board
col2: U1.28 (PB14); also elsewhere on the board
col3: U1.29 (PB15); also elsewhere on the board
col4: U1.3 (PC14); also elsewhere on the board
col5: U1.2 (PC13); also elsewhere on the board
col6: U1.46 (PB9); also elsewhere on the board
col7: U1.8 (PA0), U6.5
col8: U1.9 (PA1), U6.4
col9: U1.10 (PA2), U6.3
col10: U1.11 (PA3), U6.2
row0: U1.40 (PB3), U7.1; also elsewhere on the board
row1: U1.4 (PC15), U7.2; also elsewhere on the board
row2: U1.12 (PA4), U7.3; also elsewhere on the board
row3: U1.16 (PB0), U7.4; also elsewhere on the board
row4: U1.17 (PB1), U7.5; also elsewhere on the board
row5: U1.22 (PB10); also elsewhere on the board
row6: U1.18 (PB2); also elsewhere on the board

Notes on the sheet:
Power Regulation
Decoupling Capacitors
USB-C 2.0 Port 5.1k resistors to GND on both CC pins indicate that this device is acting in legacy 2.0 UFP mode.
ESD, reverse polarity, and over-current protection
Split Connector
Software Debug
Level Shifter To convert the 3.3v signal to 5v for the SK6812 LEDs.
NOTE: BOOT0: L=0.99V, H=2.31V nRST: L=0.99V, H=2.31V RC network value designed to ensure that at time of sampling: nRST=2.31V=H, BOOT0=2.75V=H
Reset Circuit
LCD Display

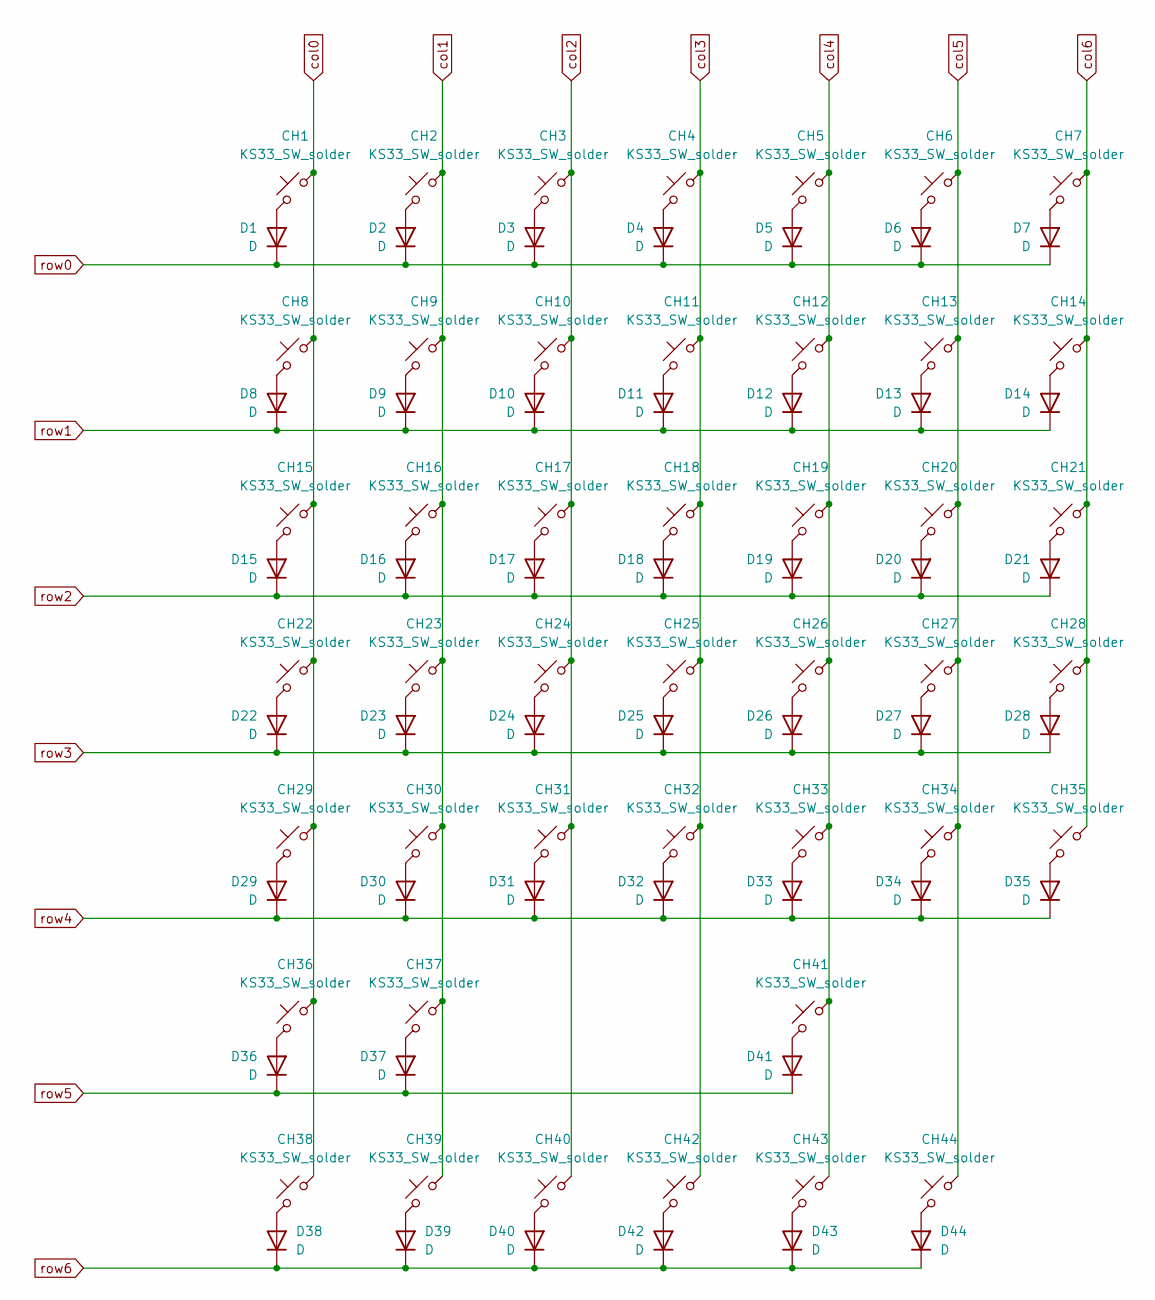
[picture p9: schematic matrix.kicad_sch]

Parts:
CH1, CH2, CH3, CH4, CH5, CH6, CH8, CH9, CH10, CH11, CH12, CH13, CH15, CH16, CH17, CH18, CH19, CH20, CH22, CH23, CH24, CH25, CH26, CH27, CH29, CH30, CH31, CH32, CH33, CH34, CH36, CH37, CH41, CH42, CH43, CH44: KS33_SW_solder; KS33_Choc-v2_HS_1U
CH7, CH14, CH21, CH28, CH35, CH38, CH39, CH40: KS33_SW_solder; KS33_Choc-v2_HS_1.5U
D1, D2, D3, D4, D5, D6, D7, D8, D9, D10, D11, D12, D13, D14, D15, D16, D17, D18, D19, D20, D21, D22, D23, D24, D25, D26, D27, D28, D29, D30, D31, D32, D33, D34, D35, D36, D37, D38, D39, D40, D41, D42, D43, D44: D; D_SOD-123

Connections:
unnamed: CH1.2, D1.2 (A)
unnamed: CH2.2, D2.2 (A)
unnamed: CH3.2, D3.2 (A)
unnamed: CH4.2, D4.2 (A)
unnamed: CH5.2, D5.2 (A)
unnamed: CH6.2, D6.2 (A)
unnamed: CH7.2, D7.2 (A)
unnamed: CH8.2, D8.2 (A)
unnamed: CH9.2, D9.2 (A)
unnamed: CH10.2, D10.2 (A)
unnamed: CH11.2, D11.2 (A)
unnamed: CH12.2, D12.2 (A)
unnamed: CH13.2, D13.2 (A)
unnamed: CH14.2, D14.2 (A)
unnamed: CH15.2, D15.2 (A)
unnamed: CH16.2, D16.2 (A)
unnamed: CH17.2, D17.2 (A)
unnamed: CH18.2, D18.2 (A)
unnamed: CH19.2, D19.2 (A)
unnamed: CH20.2, D20.2 (A)
unnamed: CH21.2, D21.2 (A)
unnamed: CH22.2, D22.2 (A)
unnamed: CH23.2, D23.2 (A)
unnamed: CH24.2, D24.2 (A)
unnamed: CH25.2, D25.2 (A)
unnamed: CH26.2, D26.2 (A)
unnamed: CH27.2, D27.2 (A)
unnamed: CH28.2, D28.2 (A)
unnamed: CH29.2, D29.2 (A)
unnamed: CH30.2, D30.2 (A)
unnamed: CH31.2, D31.2 (A)
unnamed: CH32.2, D32.2 (A)
unnamed: CH33.2, D33.2 (A)
unnamed: CH34.2, D34.2 (A)
unnamed: CH35.2, D35.2 (A)
unnamed: CH36.2, D36.2 (A)
unnamed: CH37.2, D37.2 (A)
unnamed: CH38.2, D38.2 (A)
unnamed: CH39.2, D39.2 (A)
unnamed: CH40.2, D40.2 (A)
unnamed: CH41.2, D41.2 (A)
unnamed: CH42.2, D42.2 (A)
unnamed: CH43.2, D43.2 (A)
unnamed: CH44.2, D44.2 (A)
col0: CH1.1, CH8.1, CH15.1, CH22.1, CH29.1, CH36.1, CH38.1; also elsewhere on the board
col1: CH2.1, CH9.1, CH16.1, CH23.1, CH30.1, CH37.1, CH39.1; also elsewhere on the board
col2: CH3.1, CH10.1, CH17.1, CH24.1, CH31.1, CH40.1; also elsewhere on the board
col3: CH4.1, CH11.1, CH18.1, CH25.1, CH32.1, CH42.1; also elsewhere on the board
col4: CH5.1, CH12.1, CH19.1, CH26.1, CH33.1, CH41.1, CH43.1; also elsewhere on the board
col5: CH6.1, CH13.1, CH20.1, CH27.1, CH34.1, CH44.1; also elsewhere on the board
col6: CH7.1, CH14.1, CH21.1, CH28.1, CH35.1; also elsewhere on the board
row0: D1.1 (K), D2.1 (K), D3.1 (K), D4.1 (K), D5.1 (K), D6.1 (K), D7.1 (K); also elsewhere on the board
row1: D8.1 (K), D9.1 (K), D10.1 (K), D11.1 (K), D12.1 (K), D13.1 (K), D14.1 (K); also elsewhere on the board
row2: D15.1 (K), D16.1 (K), D17.1 (K), D18.1 (K), D19.1 (K), D20.1 (K), D21.1 (K); also elsewhere on the board
row3: D22.1 (K), D23.1 (K), D24.1 (K), D25.1 (K), D26.1 (K), D27.1 (K), D28.1 (K); also elsewhere on the board
row4: D29.1 (K), D30.1 (K), D31.1 (K), D32.1 (K), D33.1 (K), D34.1 (K), D35.1 (K); also elsewhere on the board
row5: D36.1 (K), D37.1 (K), D41.1 (K); also elsewhere on the board
row6: D38.1 (K), D39.1 (K), D40.1 (K), D42.1 (K), D43.1 (K), D44.1 (K); also elsewhere on the board

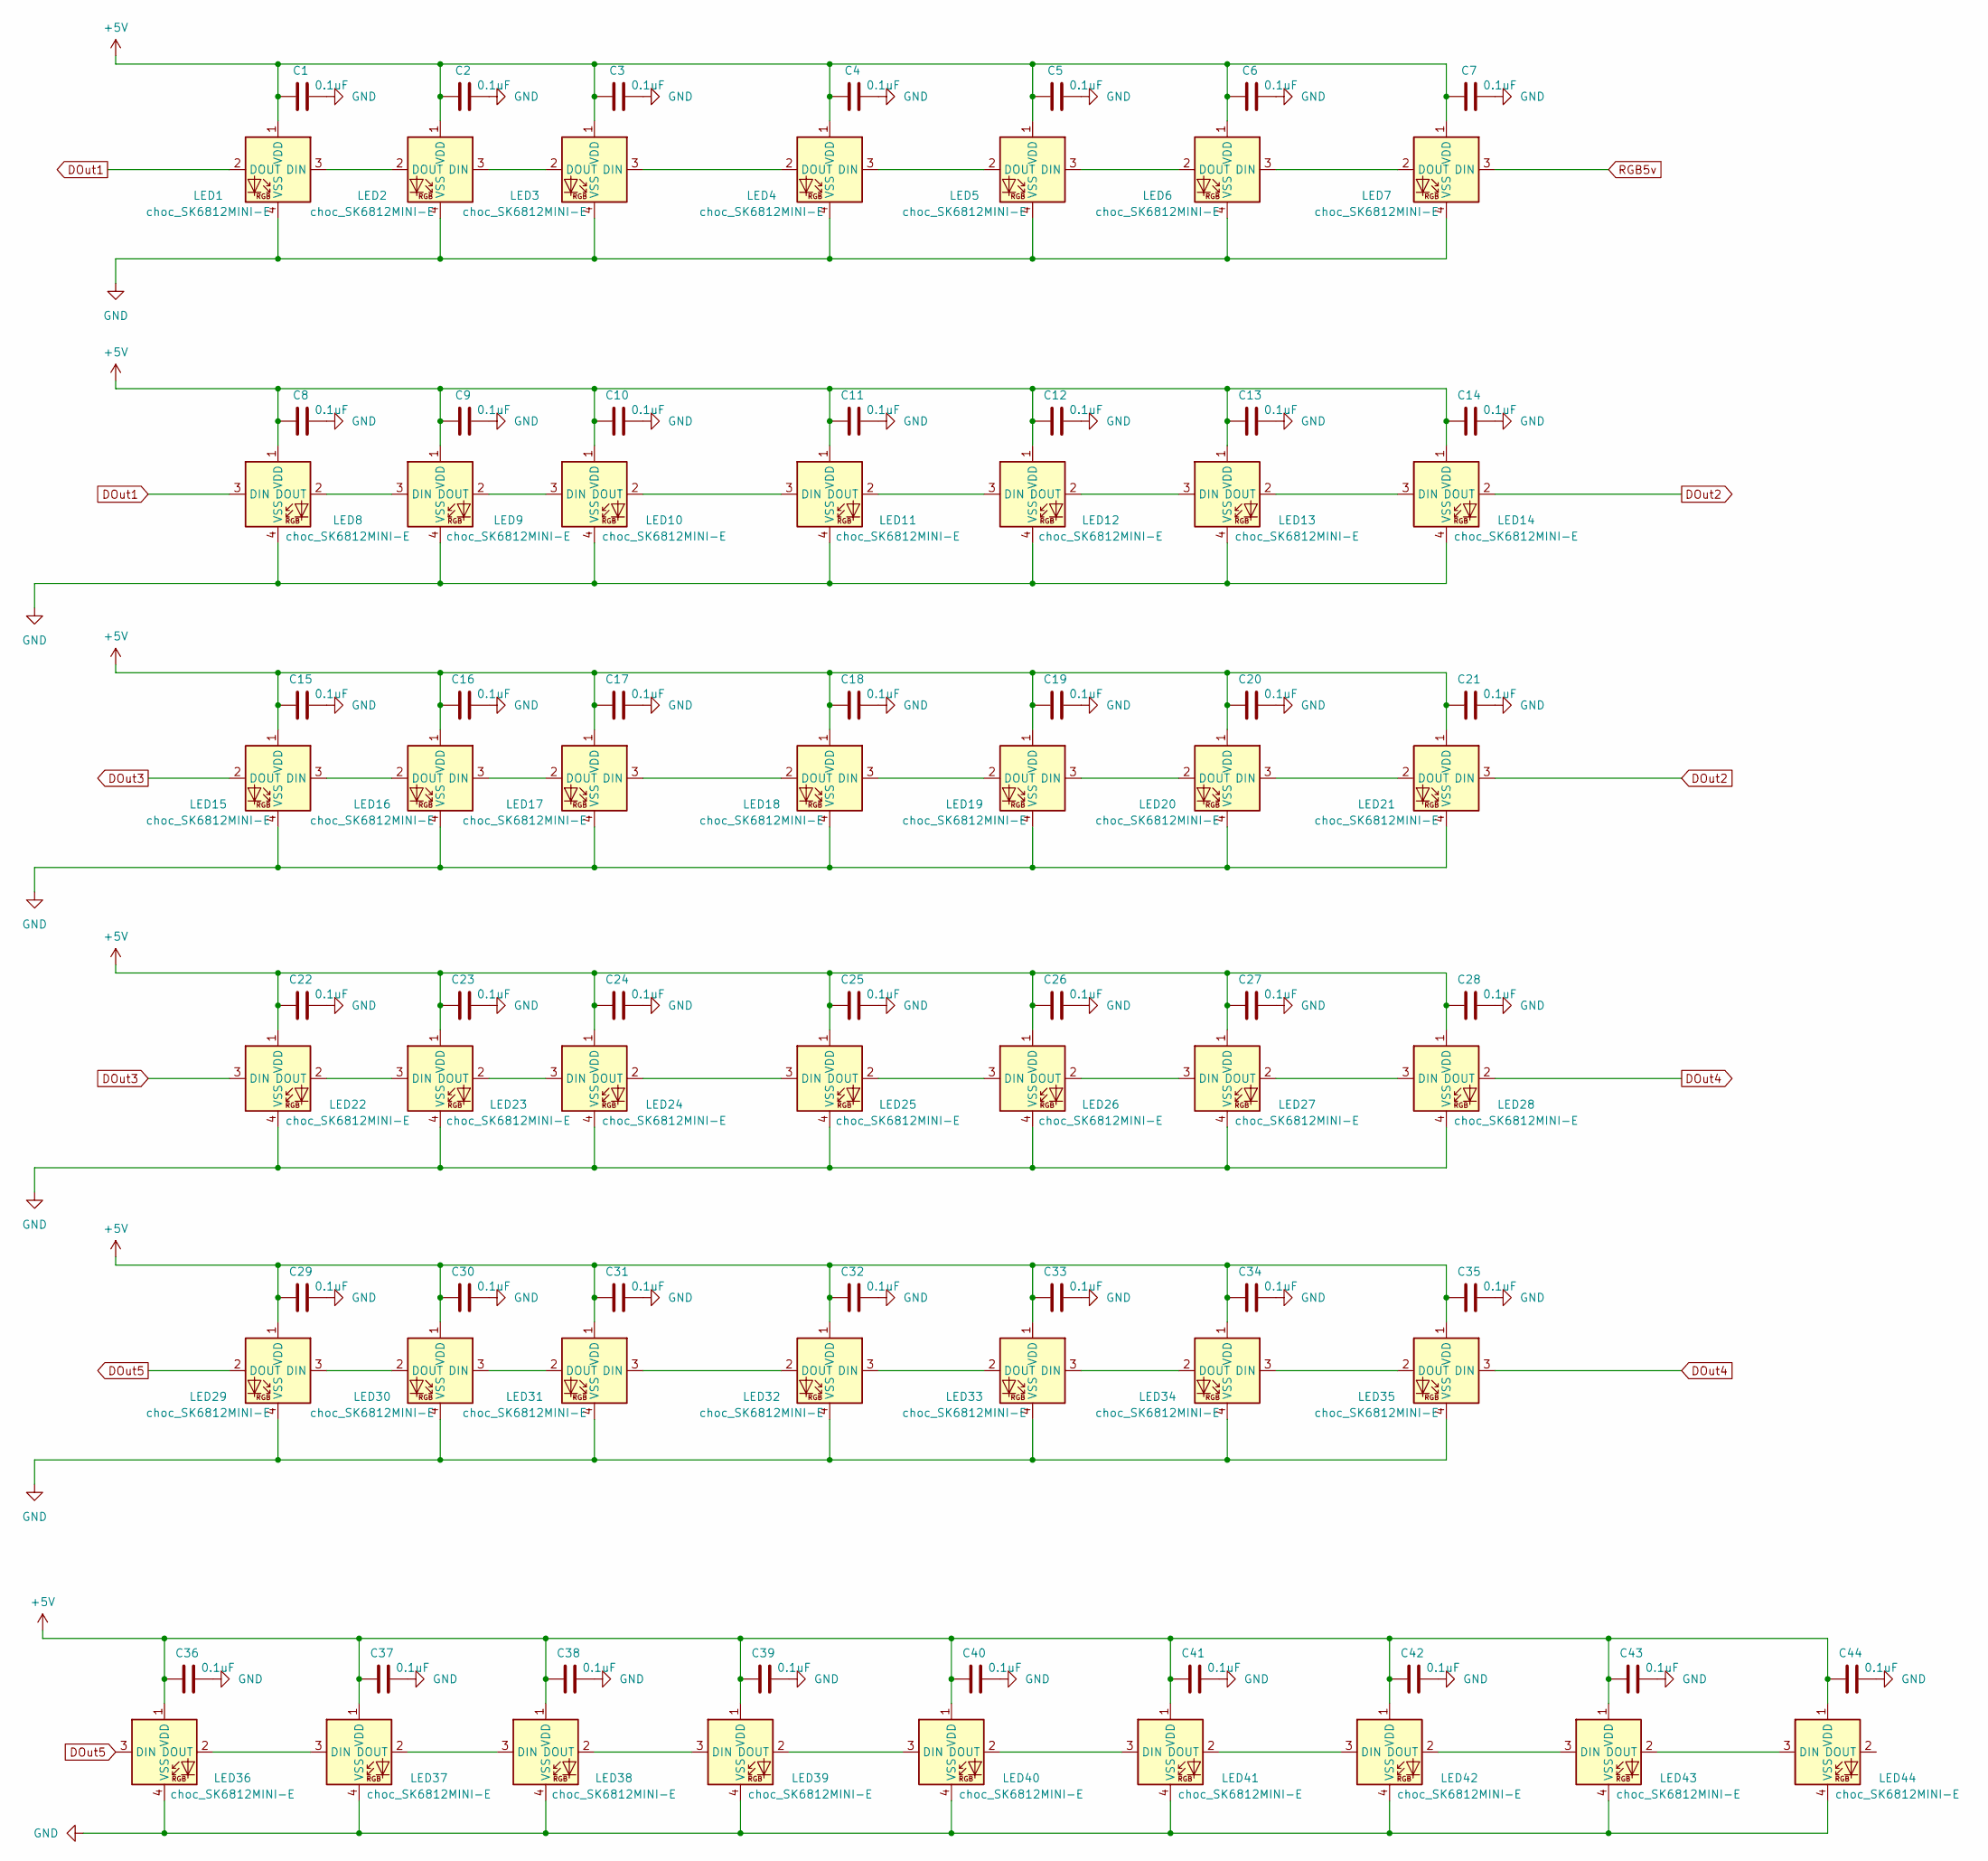
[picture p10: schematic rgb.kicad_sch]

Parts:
C1, C2, C3, C4, C5, C6, C7, C8, C9, C10, C11, C12, C13, C14, C15, C16, C17, C18, C19, C20, C21, C22, C23, C24, C25, C26, C27, C28, C29, C30, C31, C32, C33, C34, C35, C36, C37, C38, C39, C40, C41, C42, C43, C44: 0.1uF; C_0402_1005Metric
LED1, LED2, LED3, LED4, LED5, LED6, LED7, LED8, LED9, LED10, LED11, LED12, LED13, LED14, LED15, LED16, LED17, LED18, LED19, LED20, LED21, LED22, LED23, LED24, LED25, LED26, LED27, LED28, LED29, LED30, LED31, LED32, LED33, LED34, LED35, LED36, LED37, LED38, LED39, LED40, LED41, LED42, LED43, LED44: choc_SK6812MINI-E; LED_choc_6028R

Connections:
+5V: C1.1, C2.1, C3.1, C4.1, C5.1, C6.1, C7.1, C8.1, C9.1, C10.1, C11.1, C12.1, C13.1, C14.1, C15.1, C16.1, C17.1, C18.1, C19.1, C20.1, C21.1, C22.1, C23.1, C24.1, C25.1, C26.1, C27.1, C28.1, C29.1, C30.1, C31.1, C32.1, C33.1, C34.1, C35.1, C36.1, C37.1, C38.1, C39.1, C40.1, C41.1, C42.1, C43.1, C44.1, LED1.1 (VDD), LED2.1 (VDD), LED3.1 (VDD), LED4.1 (VDD), LED5.1 (VDD), LED6.1 (VDD), LED7.1 (VDD), LED8.1 (VDD), LED9.1 (VDD), LED10.1 (VDD), LED11.1 (VDD), LED12.1 (VDD), LED13.1 (VDD), LED14.1 (VDD), LED15.1 (VDD), LED16.1 (VDD), LED17.1 (VDD), LED18.1 (VDD), LED19.1 (VDD), LED20.1 (VDD), LED21.1 (VDD), LED22.1 (VDD), LED23.1 (VDD), LED24.1 (VDD), LED25.1 (VDD), LED26.1 (VDD), LED27.1 (VDD), LED28.1 (VDD), LED29.1 (VDD), LED30.1 (VDD), LED31.1 (VDD), LED32.1 (VDD), LED33.1 (VDD), LED34.1 (VDD), LED35.1 (VDD), LED36.1 (VDD), LED37.1 (VDD), LED38.1 (VDD), LED39.1 (VDD), LED40.1 (VDD), LED41.1 (VDD), LED42.1 (VDD), LED43.1 (VDD), LED44.1 (VDD); also elsewhere on the board
DOut1: LED1.2 (DOUT), LED8.3 (DIN)
DOut2: LED14.2 (DOUT), LED21.3 (DIN)
DOut3: LED15.2 (DOUT), LED22.3 (DIN)
DOut4: LED28.2 (DOUT), LED35.3 (DIN)
DOut5: LED29.2 (DOUT), LED36.3 (DIN)
GND: C1.2, C2.2, C3.2, C4.2, C5.2, C6.2, C7.2, C8.2, C9.2, C10.2, C11.2, C12.2, C13.2, C14.2, C15.2, C16.2, C17.2, C18.2, C19.2, C20.2, C21.2, C22.2, C23.2, C24.2, C25.2, C26.2, C27.2, C28.2, C29.2, C30.2, C31.2, C32.2, C33.2, C34.2, C35.2, C36.2, C37.2, C38.2, C39.2, C40.2, C41.2, C42.2, C43.2, C44.2, LED1.4 (VSS), LED2.4 (VSS), LED3.4 (VSS), LED4.4 (VSS), LED5.4 (VSS), LED6.4 (VSS), LED7.4 (VSS), LED8.4 (VSS), LED9.4 (VSS), LED10.4 (VSS), LED11.4 (VSS), LED12.4 (VSS), LED13.4 (VSS), LED14.4 (VSS), LED15.4 (VSS), LED16.4 (VSS), LED17.4 (VSS), LED18.4 (VSS), LED19.4 (VSS), LED20.4 (VSS), LED21.4 (VSS), LED22.4 (VSS), LED23.4 (VSS), LED24.4 (VSS), LED25.4 (VSS), LED26.4 (VSS), LED27.4 (VSS), LED28.4 (VSS), LED29.4 (VSS), LED30.4 (VSS), LED31.4 (VSS), LED32.4 (VSS), LED33.4 (VSS), LED34.4 (VSS), LED35.4 (VSS), LED36.4 (VSS), LED37.4 (VSS), LED38.4 (VSS), LED39.4 (VSS), LED40.4 (VSS), LED41.4 (VSS), LED42.4 (VSS), LED43.4 (VSS), LED44.4 (VSS); also elsewhere on the board
unnamed: LED1.3 (DIN), LED2.2 (DOUT)
unnamed: LED2.3 (DIN), LED3.2 (DOUT)
unnamed: LED3.3 (DIN), LED4.2 (DOUT)
unnamed: LED4.3 (DIN), LED5.2 (DOUT)
unnamed: LED5.3 (DIN), LED6.2 (DOUT)
unnamed: LED6.3 (DIN), LED7.2 (DOUT)
unnamed: LED8.2 (DOUT), LED9.3 (DIN)
unnamed: LED9.2 (DOUT), LED10.3 (DIN)
unnamed: LED10.2 (DOUT), LED11.3 (DIN)
unnamed: LED11.2 (DOUT), LED12.3 (DIN)
unnamed: LED12.2 (DOUT), LED13.3 (DIN)
unnamed: LED13.2 (DOUT), LED14.3 (DIN)
unnamed: LED15.3 (DIN), LED16.2 (DOUT)
unnamed: LED16.3 (DIN), LED17.2 (DOUT)
unnamed: LED17.3 (DIN), LED18.2 (DOUT)
unnamed: LED18.3 (DIN), LED19.2 (DOUT)
unnamed: LED19.3 (DIN), LED20.2 (DOUT)
unnamed: LED20.3 (DIN), LED21.2 (DOUT)
unnamed: LED22.2 (DOUT), LED23.3 (DIN)
unnamed: LED23.2 (DOUT), LED24.3 (DIN)
unnamed: LED24.2 (DOUT), LED25.3 (DIN)
unnamed: LED25.2 (DOUT), LED26.3 (DIN)
unnamed: LED26.2 (DOUT), LED27.3 (DIN)
unnamed: LED27.2 (DOUT), LED28.3 (DIN)
unnamed: LED29.3 (DIN), LED30.2 (DOUT)
unnamed: LED30.3 (DIN), LED31.2 (DOUT)
unnamed: LED31.3 (DIN), LED32.2 (DOUT)
unnamed: LED32.3 (DIN), LED33.2 (DOUT)
unnamed: LED33.3 (DIN), LED34.2 (DOUT)
unnamed: LED34.3 (DIN), LED35.2 (DOUT)
unnamed: LED36.2 (DOUT), LED37.3 (DIN)
unnamed: LED37.2 (DOUT), LED38.3 (DIN)
unnamed: LED38.2 (DOUT), LED39.3 (DIN)
unnamed: LED39.2 (DOUT), LED40.3 (DIN)
unnamed: LED40.2 (DOUT), LED41.3 (DIN)
unnamed: LED41.2 (DOUT), LED42.3 (DIN)
unnamed: LED42.2 (DOUT), LED43.3 (DIN)
unnamed: LED43.2 (DOUT), LED44.3 (DIN)
RGB5v: LED7.3 (DIN); also elsewhere on the board

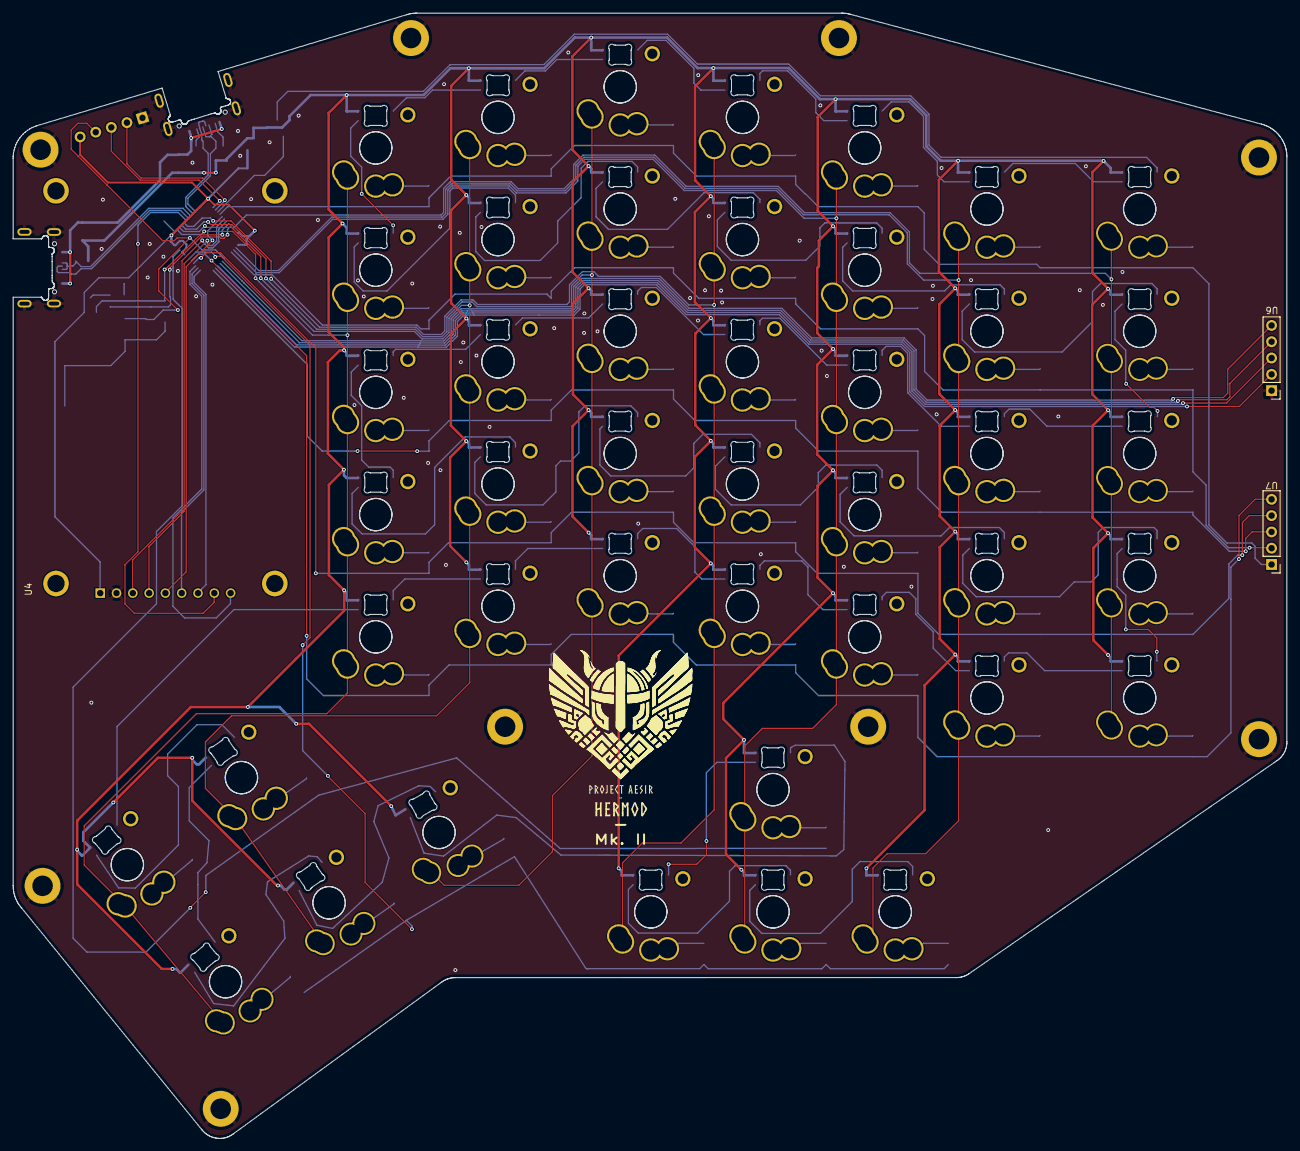
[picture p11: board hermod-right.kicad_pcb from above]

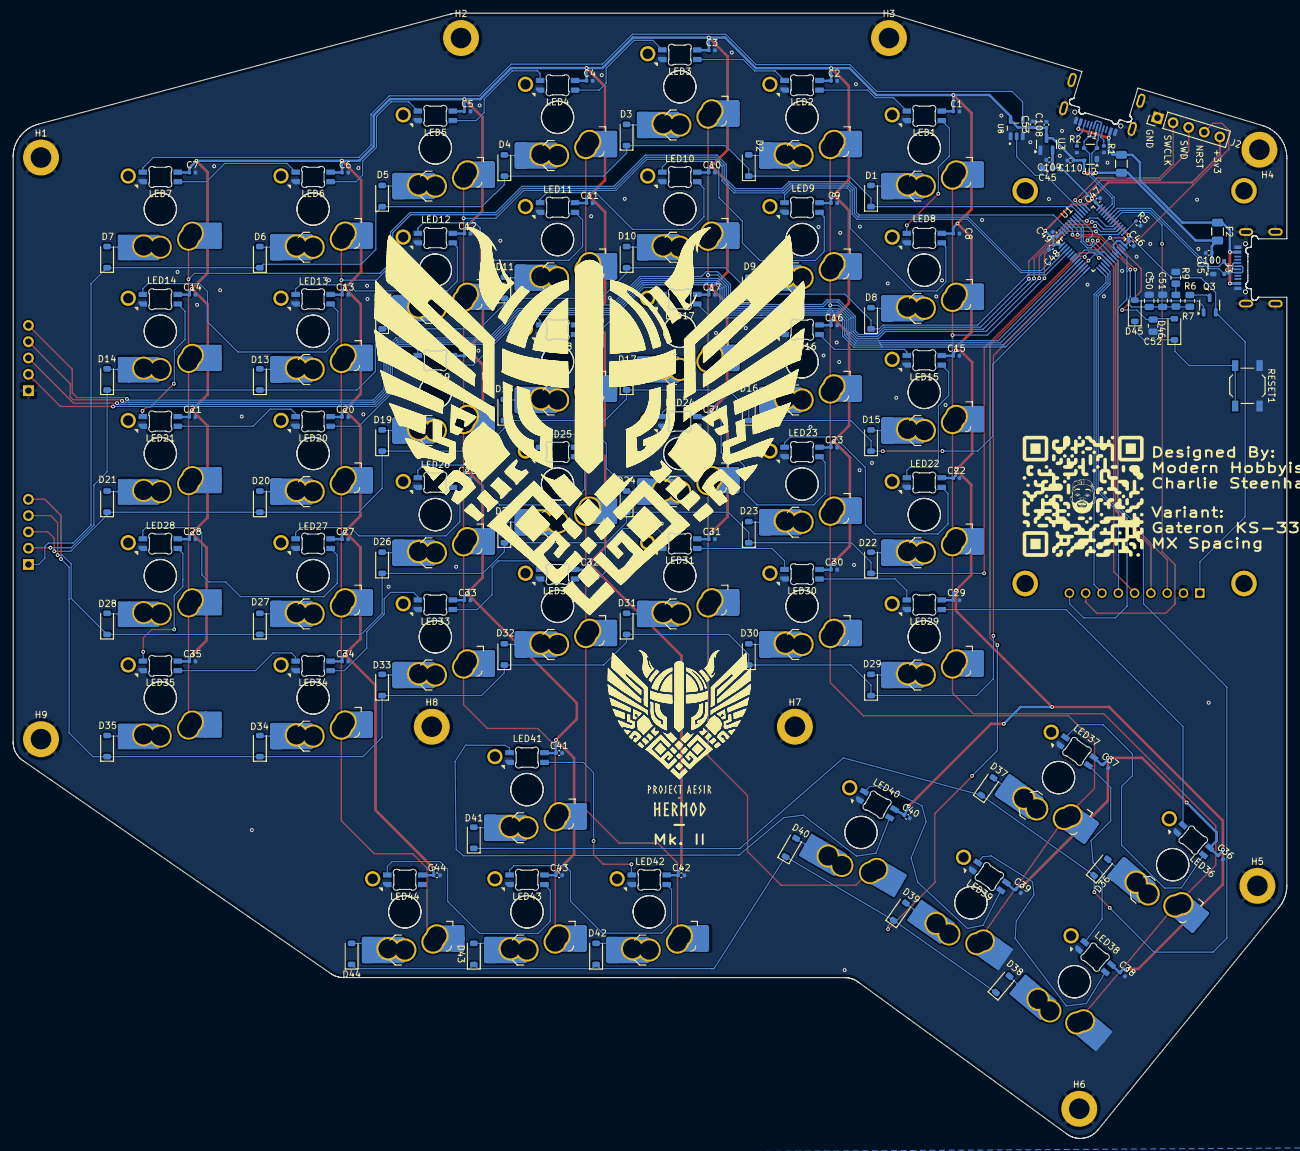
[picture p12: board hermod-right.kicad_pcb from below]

Board: 2 copper layers, 198.5 x 175.4 mm, 221 parts (218 on the bottom side), 133 nets.

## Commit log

2024-09-08 Wired the LEDs on the right
    [hermod.kicad_pcb]
2024-09-08 Wired up rows and cols
    [hermod.kicad_pcb, hermod.kicad_sch]
2024-09-08 Updated more wiring
    [hermod.kicad_pcb]
2024-09-08 Finished wiring and addressed DRC
    [hermod.kicad_pcb]
2024-09-09 Finished routing
    [hermod.kicad_pcb]
2024-09-11 Added PCBWay DRC presets
    [hermod.kicad_pcb, modern-keyboard-template.kicad_pcb]
2024-09-18 Fixed capacitor orientation
    [hermod.kicad_pcb, modern-keyboard-template.kicad_pcb, odin.kicad_pcb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]
2024-10-30 Updated extended hermod
    [hermod-plate.kicad_pcb, hermod.kicad_pcb, hermod.kicad_sch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]
2024-12-27 Finished routing the left side 100%
    [heimdall.kicad_sch, hermod-left.kicad_pcb, hermod-left.kicad_sch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]
2025-01-03 Finished hermod designs
    [hermod-left.kicad_pcb, hermod-right.kicad_pcb, hermod-right.kicad_sch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]
2025-01-04 Fixed random trace on numpad
    [hermod-left.kicad_pcb, hermod-right.kicad_pcb, numpad.kicad_pcb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]
2025-01-04 Updated logos on the boards
    [numpad.kicad_pcb]
2025-01-04 Deleted old projects and updated readme's
    [hermod-plate.kicad_pcb, hermod.kicad_pcb, hermod.kicad_sch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]
2025-01-04 Renamed to Hermod, added logos
    [hermod-left.kicad_sch, hermod-right.kicad_sch, matrix.kicad_sch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]
2025-01-04 gitignore updates
    [hermod-left-bom.csv, hermod-right-bom.csv, numpad-bom.csv]
2025-01-06 Added new version for hermod
    [hermod-left-bom.csv, hermod-left.kicad_sch, hermod-right-bom.csv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]
2025-01-06 Fixed up the 5v for LEDs
    [hermod-left.kicad_sch, hermod-right.kicad_sch]
2025-01-09 Fixed dynamic qr code
    [numpad.kicad_pcb]
2025-02-01 Fixed up hermod mk1 and updated hermod mk2
    [hermod-left.kicad_sch, hermod-right.kicad_sch]
2025-02-01 Added some labels
    [hermod-left.kicad_sch, hermod-right.kicad_sch]
2025-07-10 Updates, added UDB project
    [matrix.kicad_sch, mist.kicad_pcb, mist.kicad_sch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]
2025-07-10 Updated UDB files
    [mist.kicad_sch]
2025-07-11 Updated standoff sizes
    [mist.kicad_sch]
2025-07-17 Removed step files
    [hermod-left-bom.csv, hermod-left.kicad_sch, hermod-right-bom.csv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]
2025-07-18 UPdated Hermod Mk 2 to have ks33 and choc v2 footprints
    [matrix.kicad_sch, numpad.kicad_pcb, numpad.kicad_sch]
2025-07-18 Removed ground plane rule area
2025-07-18 Readme update
    [numpad.kicad_pcb]
2025-07-19 Update og mist, updated readmes
    [matrix.kicad_sch]
2025-07-21 Added switches to hermod 3 and updated mist thumb spacing
    [hermod-left.kicad_sch, hermod-right.kicad_sch, matrix.kicad_sch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]
2025-07-21 Fixed spacing issues
    [matrix.kicad_sch]
2025-07-21 Fixed mist to not have rotated LEDs
2025-08-06 Fixed UDB pinout, had it backwards
    [mist-bom.csv, mist.kicad_sch, paste.kicad_pcb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]
2025-11-11 Updated mist project and README
    [mist.kicad_pcb, mist.kicad_pcb_bom.csv, mist.kicad_pcb_positions.csv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]
2025-11-19 Removed PCBWay production folder
    [mist.kicad_pcb_bom.csv, mist.kicad_pcb_positions.csv]
2025-12-01 Added north facing version of hermod and mist
    [hermod-left-bom.csv, hermod-left.kicad_sch, hermod-right-bom.csv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]
2025-12-08 Fixed cap annotations
    [matrix.kicad_sch, mist.kicad_sch, rgb.kicad_sch]
2025-12-09 Cleaned up mist, added better stab footprints
    [matrix.kicad_sch]
2025-12-09 Fixed footprints for ks33/mx stabs
2025-12-10 Updated footprint for mx/ks33 stabs again
2025-12-12 More cleanup
    [mist.kicad_sch]
2025-12-18 Updated footprints for mk2-mx
2025-12-18 Added footprints
2025-12-20 Cleaned up footprints
2025-12-22 Fixed fucked up left PCB
2025-12-22 Fixed masking issue with PCBs
    [matrix.kicad_sch]
2025-12-23 Adjusted ILI9341 footprint 3d model
2025-12-30 Updated hermod-mk2-mx
    [hermod-left.kicad_pcb, hermod-right.kicad_pcb, numpad.kicad_pcb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]
2025-12-30 Updated numpad for hermod-mk2-mk-north
    [numpad.kicad_pcb]
2025-12-30 Moved and organized hermod files
    [hermod-left-bom.csv, hermod-left.kicad_pcb, hermod-left.kicad_sch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]
2025-12-31 Switched to SRV05-4
    [hermod-left.kicad_pcb, hermod-left.kicad_sch, hermod-right.kicad_pcb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]
